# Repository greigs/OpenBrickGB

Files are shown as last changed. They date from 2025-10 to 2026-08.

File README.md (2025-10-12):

[For more info visit the hackaday writeup](https://hackaday.io/project/204088-lego-game-boy-functional-upgrade)

Watch the video (https://www.youtube.com/watch?v=JiDrCRSRUHM)

### Directory overview

- 3D Printed Parts: STL files for custom spacers and assemblies used inside the LEGO shell.
- Bill of Materials: CSVs listing components for the main PCB, button PCBs, and other parts.
- ButtonBoard PCBs: KiCad project assets and Gerbers for the button and D‑pad PCBs.
- Datasheets: Reference PDFs for key components (LCD, charger, amp, logic, regulators, etc.).
- Main PCB: KiCad project, fabrication outputs (Gerbers/DRLs), and pick‑and‑place (CPL) for the main board.
- Reference 3D Models: OBJ files used for fit checks and visualization of assemblies.
- Reference Bricklink Studio Designs: BrickLink Studio `.io` design files and a reference image for the LEGO build.

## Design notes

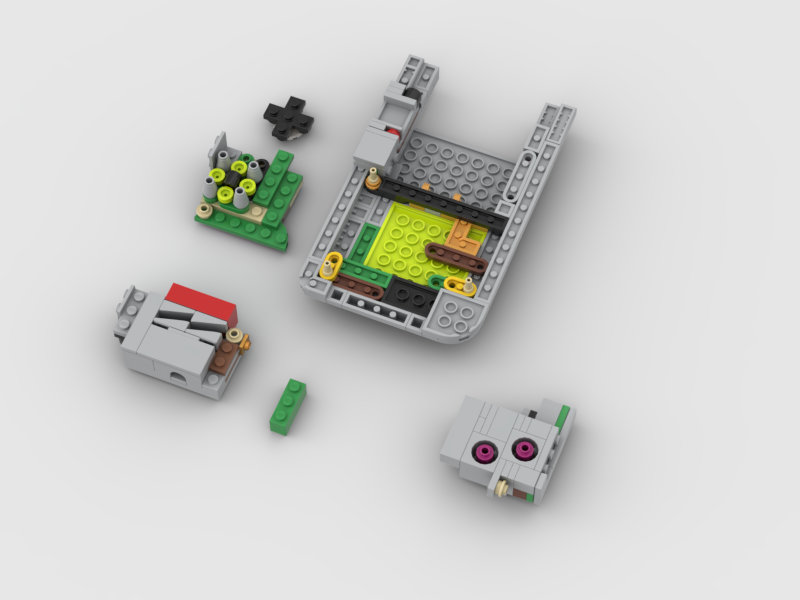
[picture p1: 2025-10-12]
Reference Bricklink Studio Designs/legogameboy_brick.png

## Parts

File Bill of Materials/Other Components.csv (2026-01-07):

Comment | Model Number | Supplier | Link | JLCPCB Part # | Quantity
2.4" LCD Screen | ER-TFT024-3 | AliExpress | https://www.aliexpress.com/item/1005008083677084.html | - | 1
USB-C Low-Profile Extension | CMZW-CF | AliExpress | https://www.aliexpress.com/item/1005008675001524.html | - | 1
Battery with PH connector | 702025 300mAh | AliExpress | https://www.aliexpress.com/item/1005009296674098.html | - | 1
Silicon Membranes for A+B buttons | - | AliExpress | https://www.aliexpress.com/item/1005007354534629.html | - | 1
LEGO Part: BRICK W. BOW (Any Colour) | 4490 | Brick Owl | https://www.brickowl.com/gb/catalog/lego-arch-1-x-3-4490 | - | 1
LEGO Part | TBD | LEGO |  | - | ?
Speaker | CMS-160903-18SP-X8 | DigiKey | https://www.digikey.co.uk/en/products/detail/same-sky-formerly-cui-devices/CMS-160903-18SP-X8/18742602 | - | 1
JST SUR Wire Jumper - 8p | A08SUR08SUR32W152A | DigiKey | https://www.digikey.co.uk/en/products/detail/jst-sales-america-inc/A08SUR08SUR32W152A/6009356 |  | 1
JST SUR Wire Jumper - 3p | A03SUR03SUR32W152B | DigiKey | https://www.digikey.co.uk/en/products/detail/jst-sales-america-inc/A03SUR03SUR32W152B/6708450 |  | 1
3M double sided adhesive | - | Stationary Shop? |  | - | 1
3D printed Part: Support for A+B Buttonboard | - | - | https://github.com/greigs/legogb/blob/main/3D%20Printed%20Parts/a_b_buttons_assembly%20v19.stl |  | 1
3D printed Part: Start + Select button assembly | - | - | https://github.com/greigs/legogb/blob/main/3D%20Printed%20Parts/start_select_assembly_with_tires%20v29.stl |  | 1
3D printed Part: USB-C Socket Housing (optional) | - | - |  | - | 1
3D printed Part: Menu Button custom Lego Piece | - | - | TBD | - | 1
3D printed Part: D-pad Spacer replacement | - | - | TBD | - | 4
MicroSD card - FAT32 Formatted | - | - | - | - | 1
Black card for covering LCD bezels (optional) | - | Stationary Shop? | - | - | 1

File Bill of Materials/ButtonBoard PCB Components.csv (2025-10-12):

Comment | Designator | Footprint | JLCPCB Part # | Purpose / Detail | Quantity
SKRRABE010 |  |  | C125046 | Low-profile tact-switch - NOTE The A + B buttons don't use these - use rubber domes instead | 6

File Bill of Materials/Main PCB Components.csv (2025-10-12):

Comment | Designator | Footprint | JLCPCB Part # | Purpose / Detail | Quantity
Conn_01x03_Socket | J6 | Connector_JST:JST_SUR_BM03B-SURS-TF_1x03-1MP_P0.80mm_Vertical | C594379 | Connector for A+B buttonboard | 1
DISP_LCD_240X320_50PIN-2.4IN | U$10 | Adafruit2.4inTFTBreakout:TFT_2.4IN_240X320_50PIN | C2828061 | 50-Pin LCD Connector | 1
USB_C_Receptacle_USB2.0_16P | J1 | Connector_USB:USB_C_Receptacle_G-Switch_GT-USB-7025 | C963213 | USB-C for power + flashing firmware | 1
MAX98357A | U4 | Package_DFN_QFN:TQFN-16-1EP_3x3mm_P0.5mm_EP1.23x1.23mm | C910544 | Sound Amplifier | 1
0.1uF | C6,C11 | Capacitor_SMD:C_0603_1608Metric | C14663 | Passive | 2
0.1nF | C8,C9 | Capacitor_SMD:C_0603_1608Metric | C14858 | Passive | 2
LED-RED | D1 | LED_SMD:LED_0603_1608Metric | C2286 | Battery Charge Indicator LED | 1
LED-GRN | D2 | LED_SMD:LED_0603_1608Metric | C2286 | Power On Indicator LED | 1
TLV75801PDRV | U2 | Package_SON:WSON-6-1EP_2x2mm_P0.65mm_EP1x1.6mm | C2876308 | Voltage Regulator | 1
1.5k | R6,R7 | Resistor_SMD:R_0603_1608Metric | C22843 | Passive | 2
ESD7104MUTAG | U3 | UDFN10_ONS | C328026 | ESD Protection | 1
B2B-PH-K-S | J3 | Connector_JST:JST_PH_S2B-PH-K_1x02_P2.00mm_Horizontal | C157932 | PH Battery Connector | 1
10uF | C4,C7 | Capacitor_SMD:C_0603_1608Metric | C19702 | Passive | 2
POWER_SW | S1 | 450404015514:450404015514 | C5446870 | Power Slide Switch | 1
BOOT | SW3,SW1 | TS-1088-AR02016:SW_TS-1088-AR02016 | C720477 | ESP32 Boot mode + Reset buttons | 2
ESP32-S3-WROOM-1-N16R8 | X1 | ESP32:ESP32S3WROOM1N8R2 | C2913202 | Main SoC | 1
200k | R3 | Resistor_SMD:R_0603_1608Metric | C25811 | Passive | 1
10 | R8 | Resistor_SMD:R_0603_1608Metric | C22859 | Passive | 1
5k | R4 | Resistor_SMD:R_0603_1608Metric | C2828621 | Passive | 1
503398-1892 | J4 | MOLEX_503398-1892:MOLEX_503398-1892 | C428492 | Passive | 1
~ | SW2 | ProLib_pcs_2025-10-09:SW-SMD_GT-TC185B-H038-L1 | C778160 | Menu Button | 1
1M | R2 | Resistor_SMD:R_0603_1608Metric | C22935 | Passive | 1
1uF | C1,C2,C3,C5,C10 | Capacitor_SMD:C_0603_1608Metric | C15849 | Passive | 5
BQ24040DSQR | U1 | BQ24040DSQR:SON40P200X200X80-11N | C81080 | Battery Management | 1
10k | R1,R5,R9,R10,R11,R12,R13,R14,R15,R16 | Resistor_SMD:R_0603_1608Metric | C25804 | Passive | 10
100k | R17 | Resistor_SMD:R_0603_1608Metric | C25803 | Passive | 1
Conn_01x08_Socket | J2 | Connector_JST:JST_SUR_BM08B-SURS-TF_1x08-1MP_P0.80mm_Vertical | C5143489 | Connector for select + start + D-pad boards | 1

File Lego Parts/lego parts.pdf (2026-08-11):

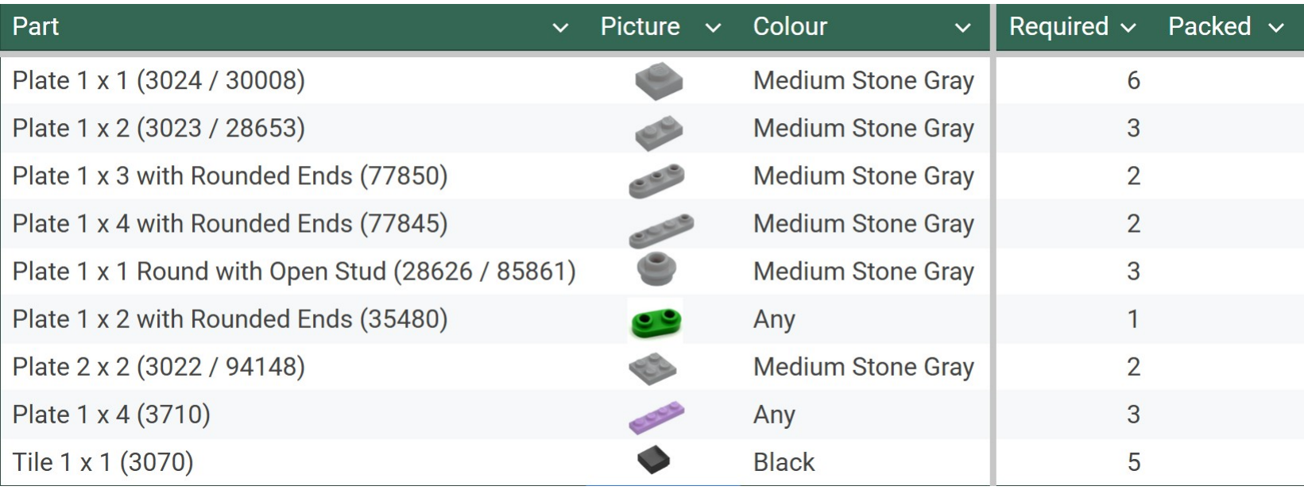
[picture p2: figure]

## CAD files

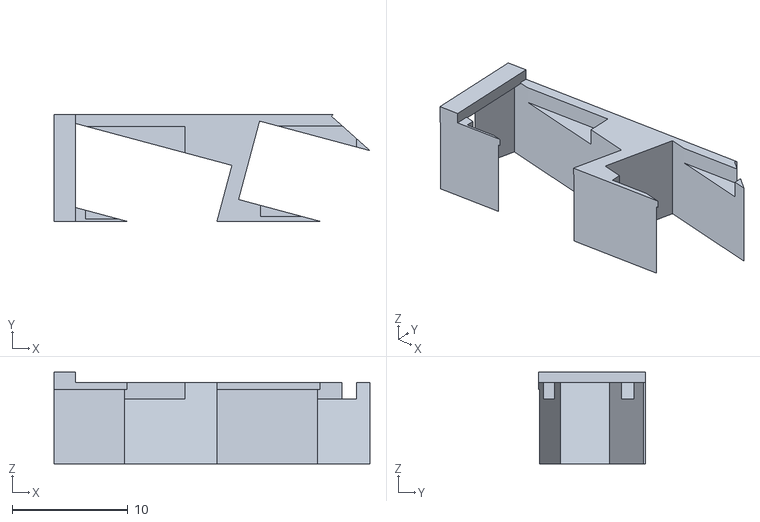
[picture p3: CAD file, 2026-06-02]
3D Printed Parts/start_select_assembly.stl
27.2 x 9.20 x 7.90

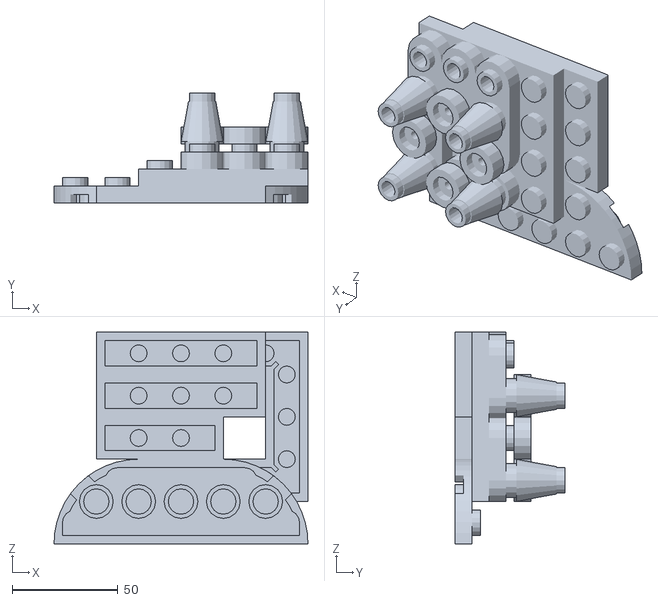
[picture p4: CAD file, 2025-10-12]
Reference 3D Models/d_pad_assembly.obj
120.0 x 52.0 x 100.0

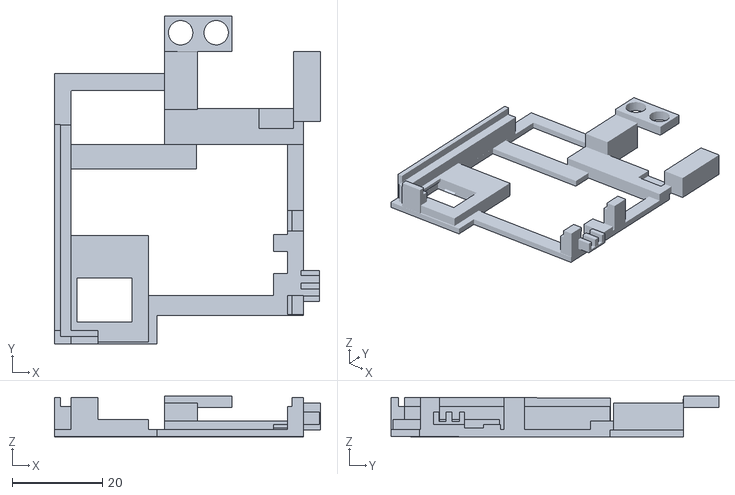
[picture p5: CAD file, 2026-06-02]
3D Printed Parts/main_frame.stl
59.0 x 72.7 x 9.06

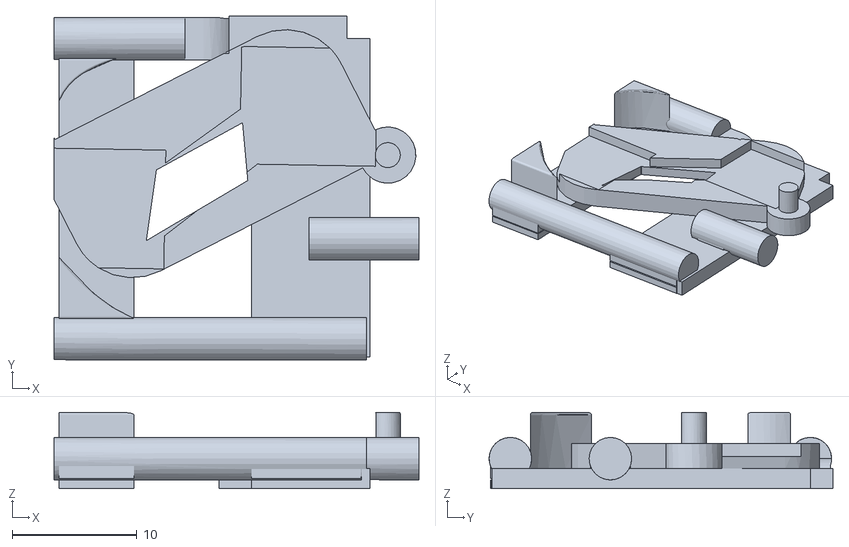
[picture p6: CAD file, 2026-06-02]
3D Printed Parts/a_b_buttons_assembly.stl
29.2 x 27.5 x 6.10

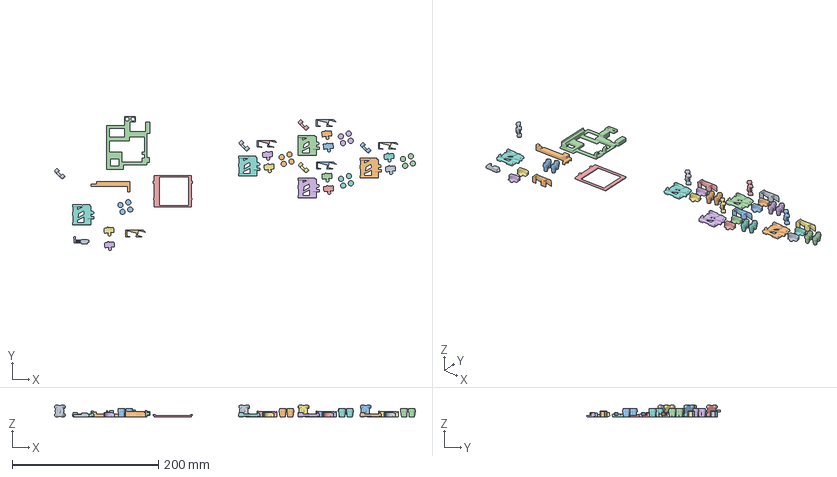
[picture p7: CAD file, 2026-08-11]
3D Printed Parts/All_Parts_v1.3mf
493.3 x 183.3 x 15.9 mm
d-pad-pivot_v20.stl x 5
spacer_6.stl
Assembly x 5
pcb_holder-speaker-5.stl
shrowd_1.stl
tire_holder_v53.stl x 10
a_b_buttons_assembly_v46.stl x 5
actuator_3.stl
start_select_assembly.stl x 5

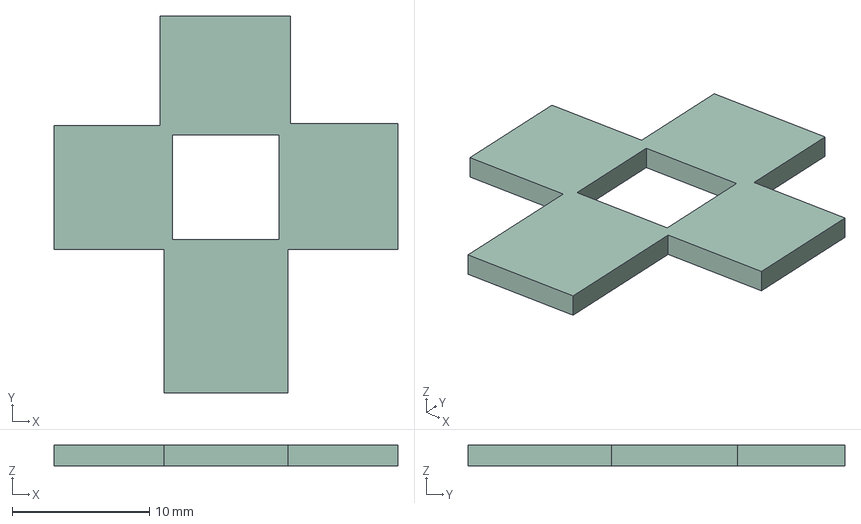
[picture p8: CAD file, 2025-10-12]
ButtonBoard PCBs/lego-gameboy-buttonboards.step
25.0 x 27.4 x 1.51 mm

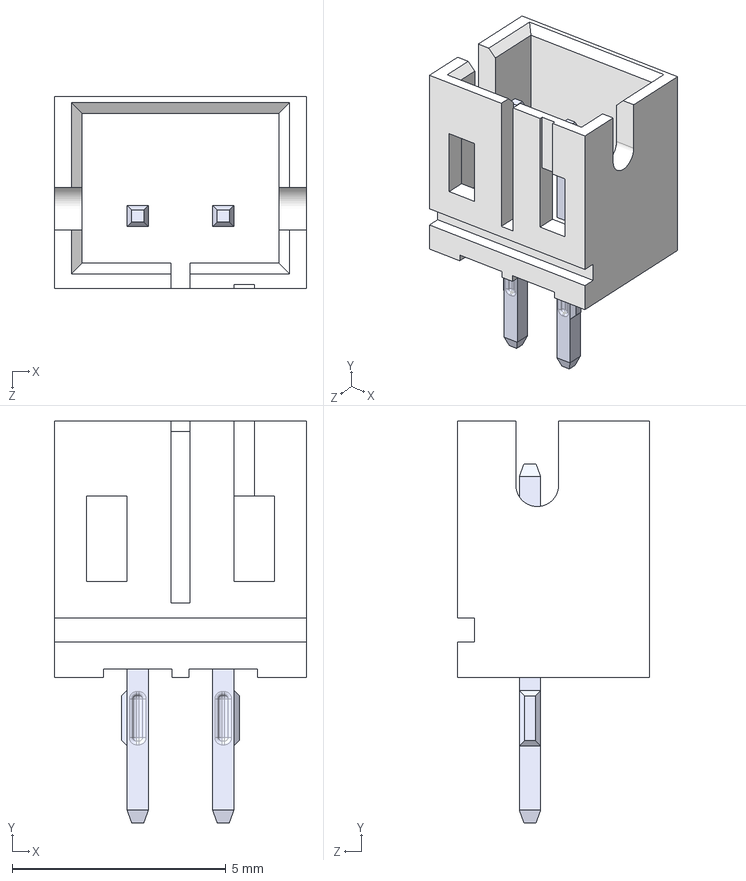
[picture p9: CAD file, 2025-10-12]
Main PCB/Kicad Components/B2B-PH-K-S/B2B-PH-K-S.step
5.90 x 9.40 x 4.50 mm

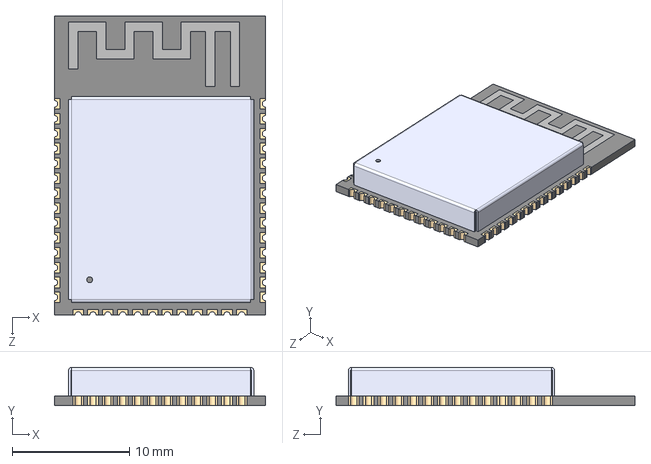
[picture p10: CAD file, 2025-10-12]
Main PCB/Kicad Components/ESP32/ESP32-S3-WROOM-1-N16R8.step
18.0 x 3.25 x 25.5 mm

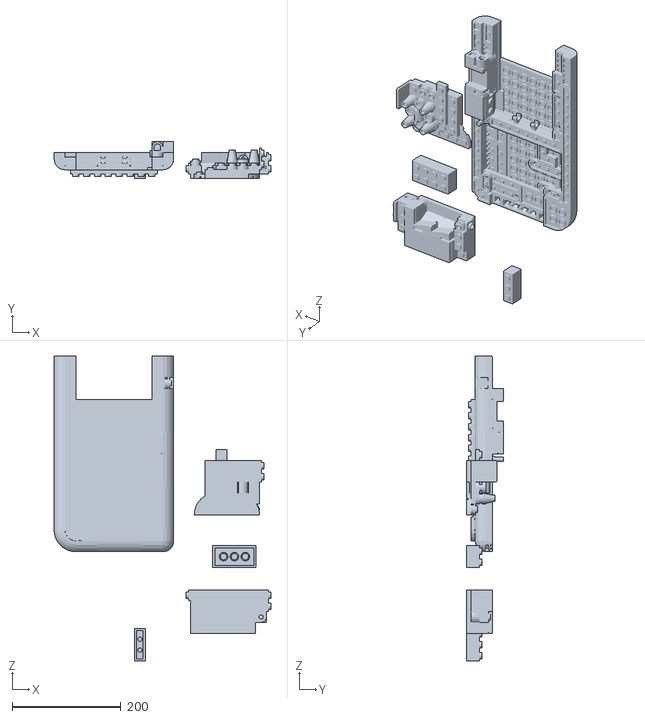
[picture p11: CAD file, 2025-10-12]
Reference 3D Models/lego_gameboy.obj
398.7 x 67.8 x 561.0

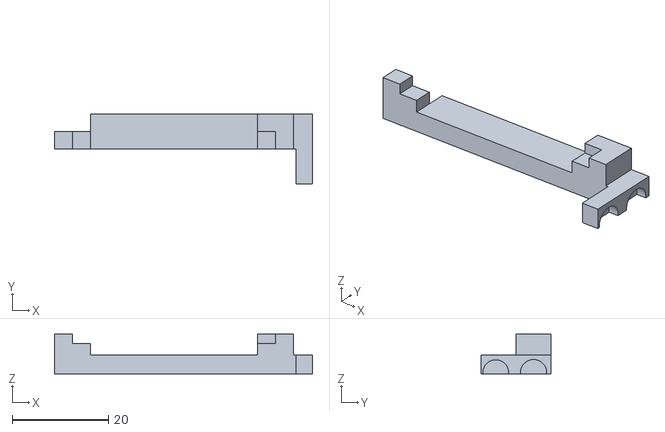
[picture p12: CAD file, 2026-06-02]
3D Printed Parts/lcd_support.stl
53.6 x 14.6 x 8.27

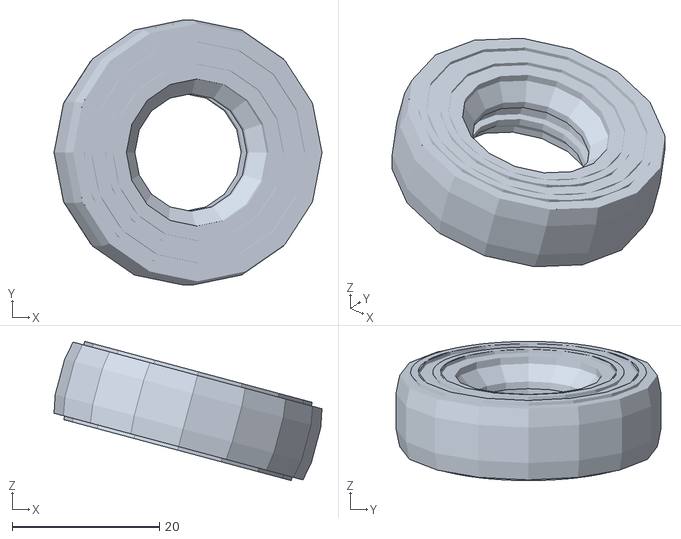
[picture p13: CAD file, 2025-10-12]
Reference 3D Models/tire.obj
36.4 x 36.0 x 18.9

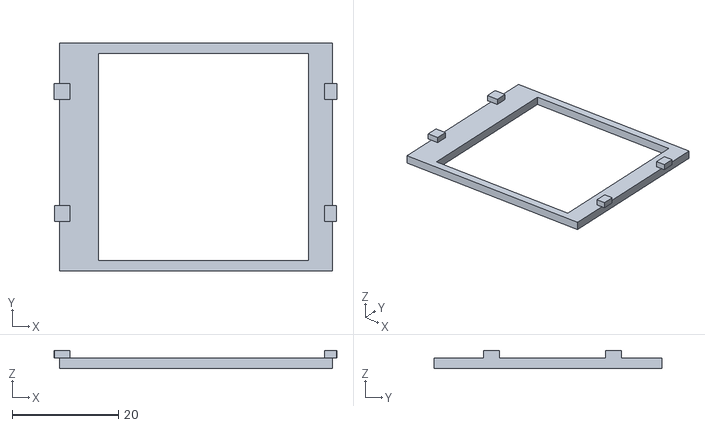
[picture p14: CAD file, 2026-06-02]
3D Printed Parts/screen_shrowd.stl
53.3 x 43.0 x 3.40

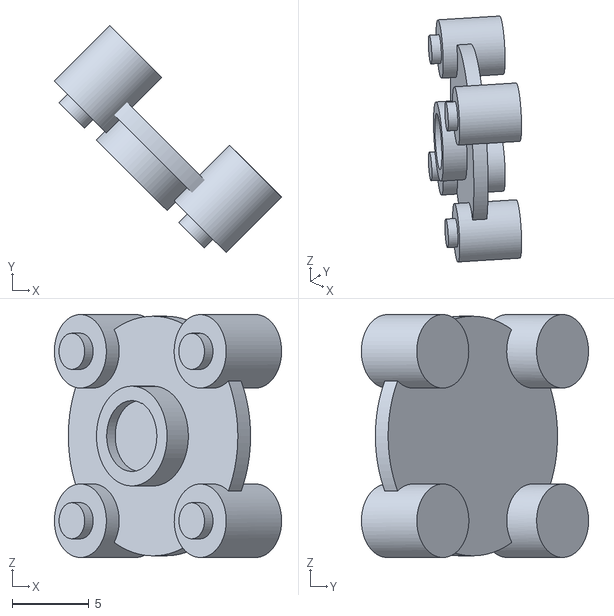
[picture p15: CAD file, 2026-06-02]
3D Printed Parts/dpad_support.stl
14.8 x 14.8 x 15.9

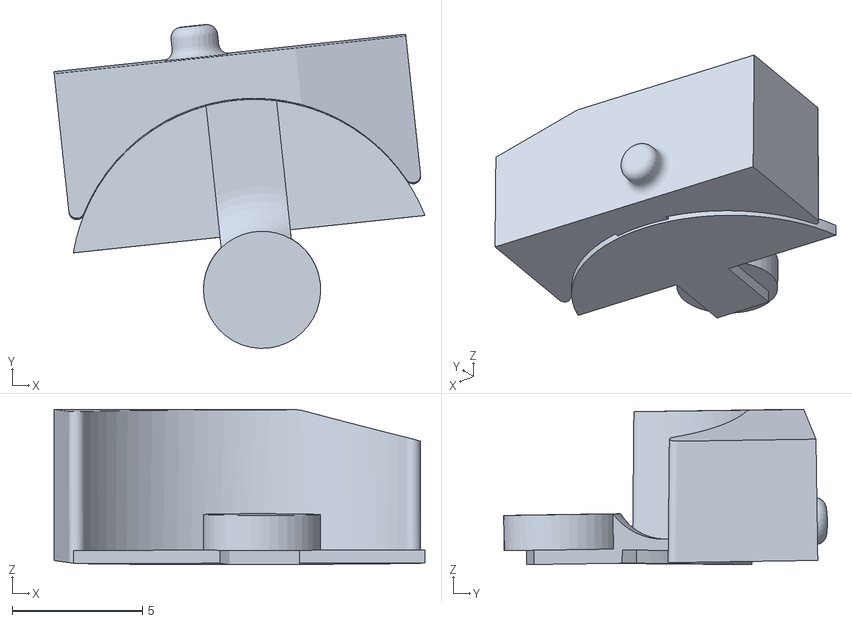
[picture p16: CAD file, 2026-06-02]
3D Printed Parts/tire_holder.stl
14.2 x 12.4 x 5.96

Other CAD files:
3D Printed Parts/cone.stl
3D Printed Parts/actuator.stl
Main PCB/Kicad Components/450404015514/450404015514.step
Main PCB/Kicad Components/BQ24040DSQR/BQ24040DSQR.step

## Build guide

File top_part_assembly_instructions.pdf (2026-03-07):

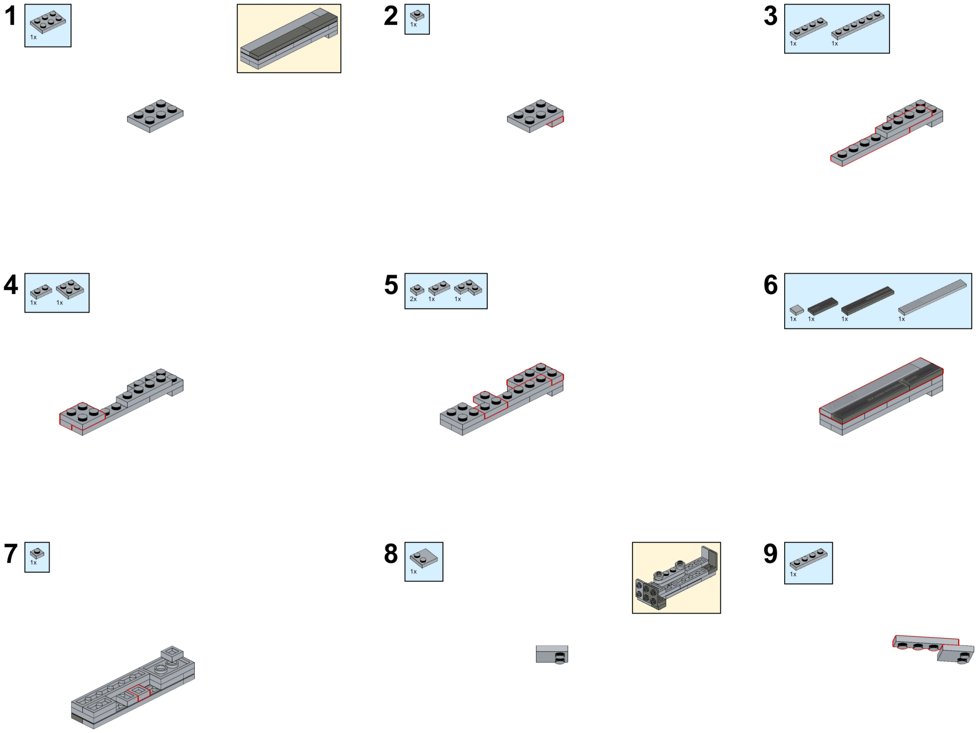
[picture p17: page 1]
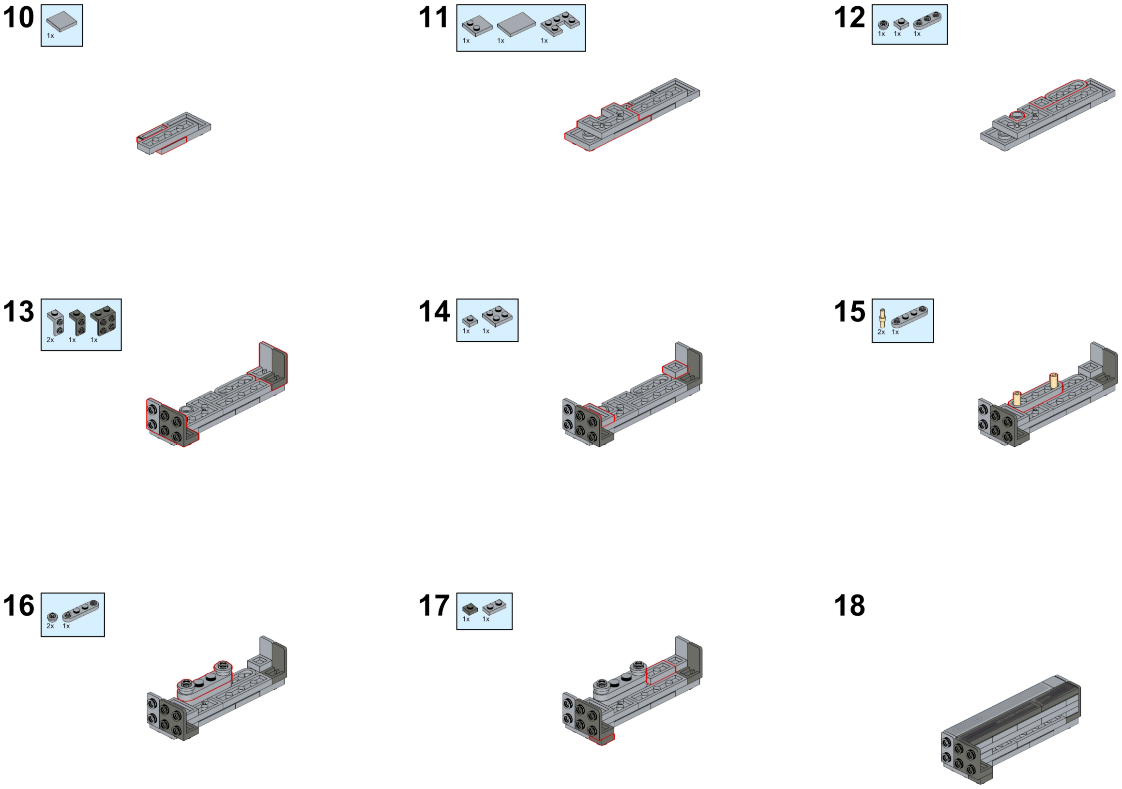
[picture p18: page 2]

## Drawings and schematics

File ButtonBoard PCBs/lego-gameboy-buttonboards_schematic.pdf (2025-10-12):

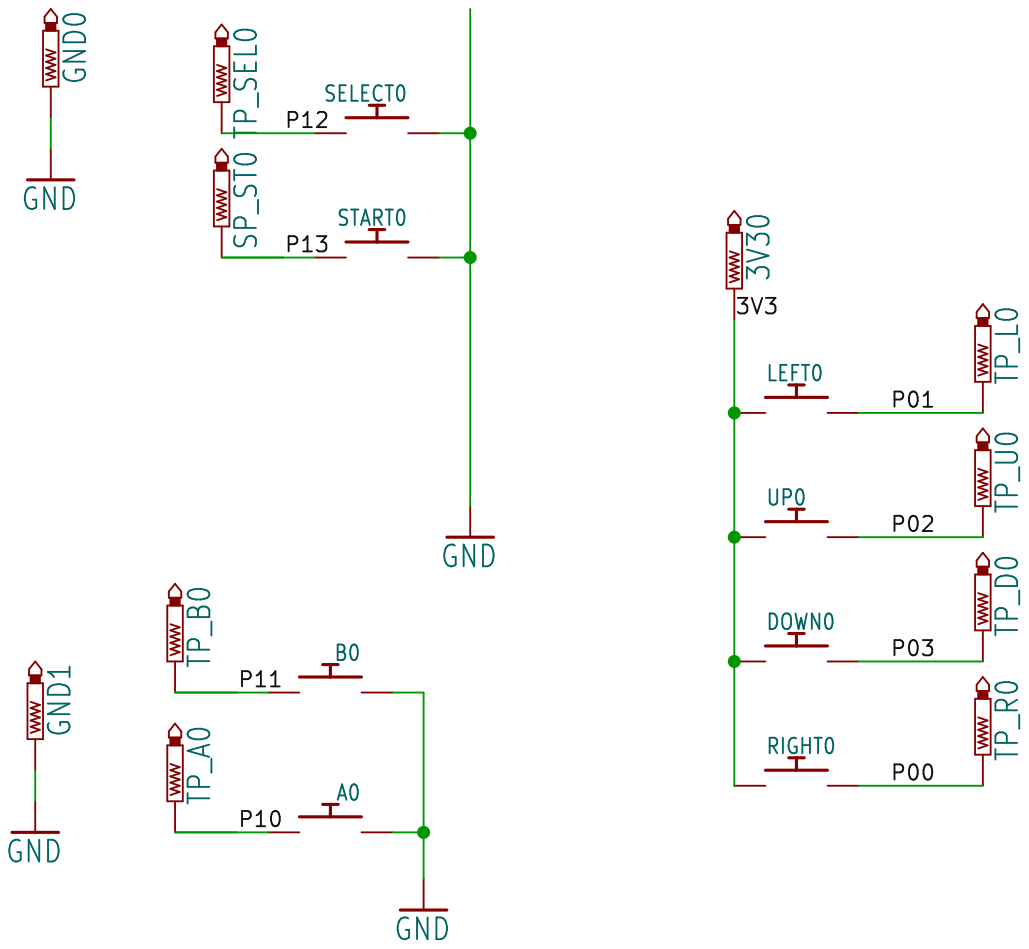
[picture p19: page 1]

Id: 1/1 Title: Lego Game Boy Button Boards

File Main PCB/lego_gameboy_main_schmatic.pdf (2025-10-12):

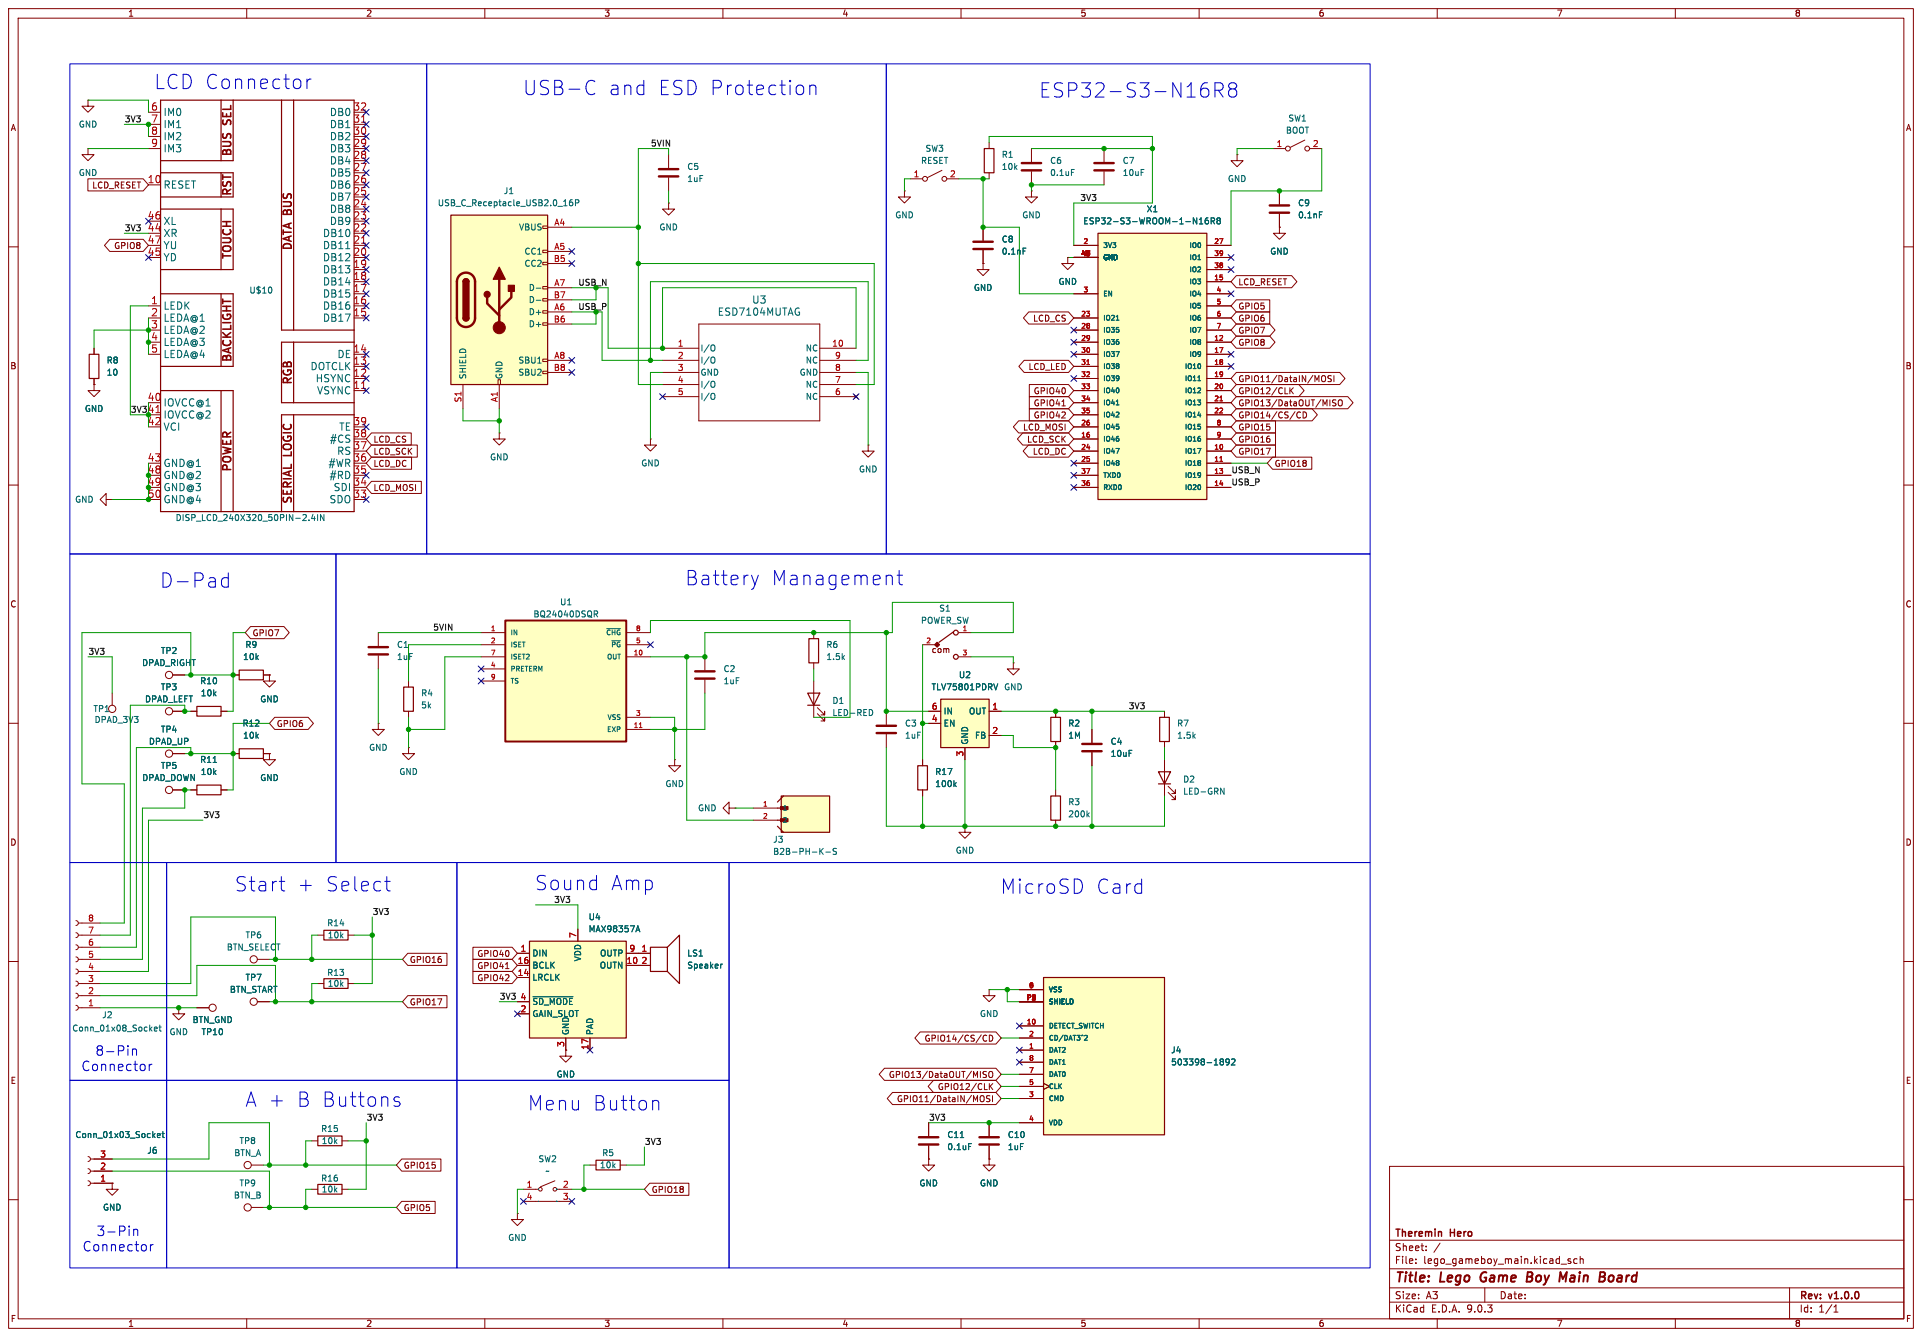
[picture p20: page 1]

USB-C and ESD Protection

GPIO11/DataIN/MOSI GPIO12/CLK GPIO15 GPIO14/CS/CD GPIO16 GPIO17

7 PAD 17 OUTP 9 OUTN 10 U4 MAX98357A GND GND

GPIO14/CS/CD GPIO13/DataOUT/MISO

Id: 1/1 Title: Lego Game Boy Main Board

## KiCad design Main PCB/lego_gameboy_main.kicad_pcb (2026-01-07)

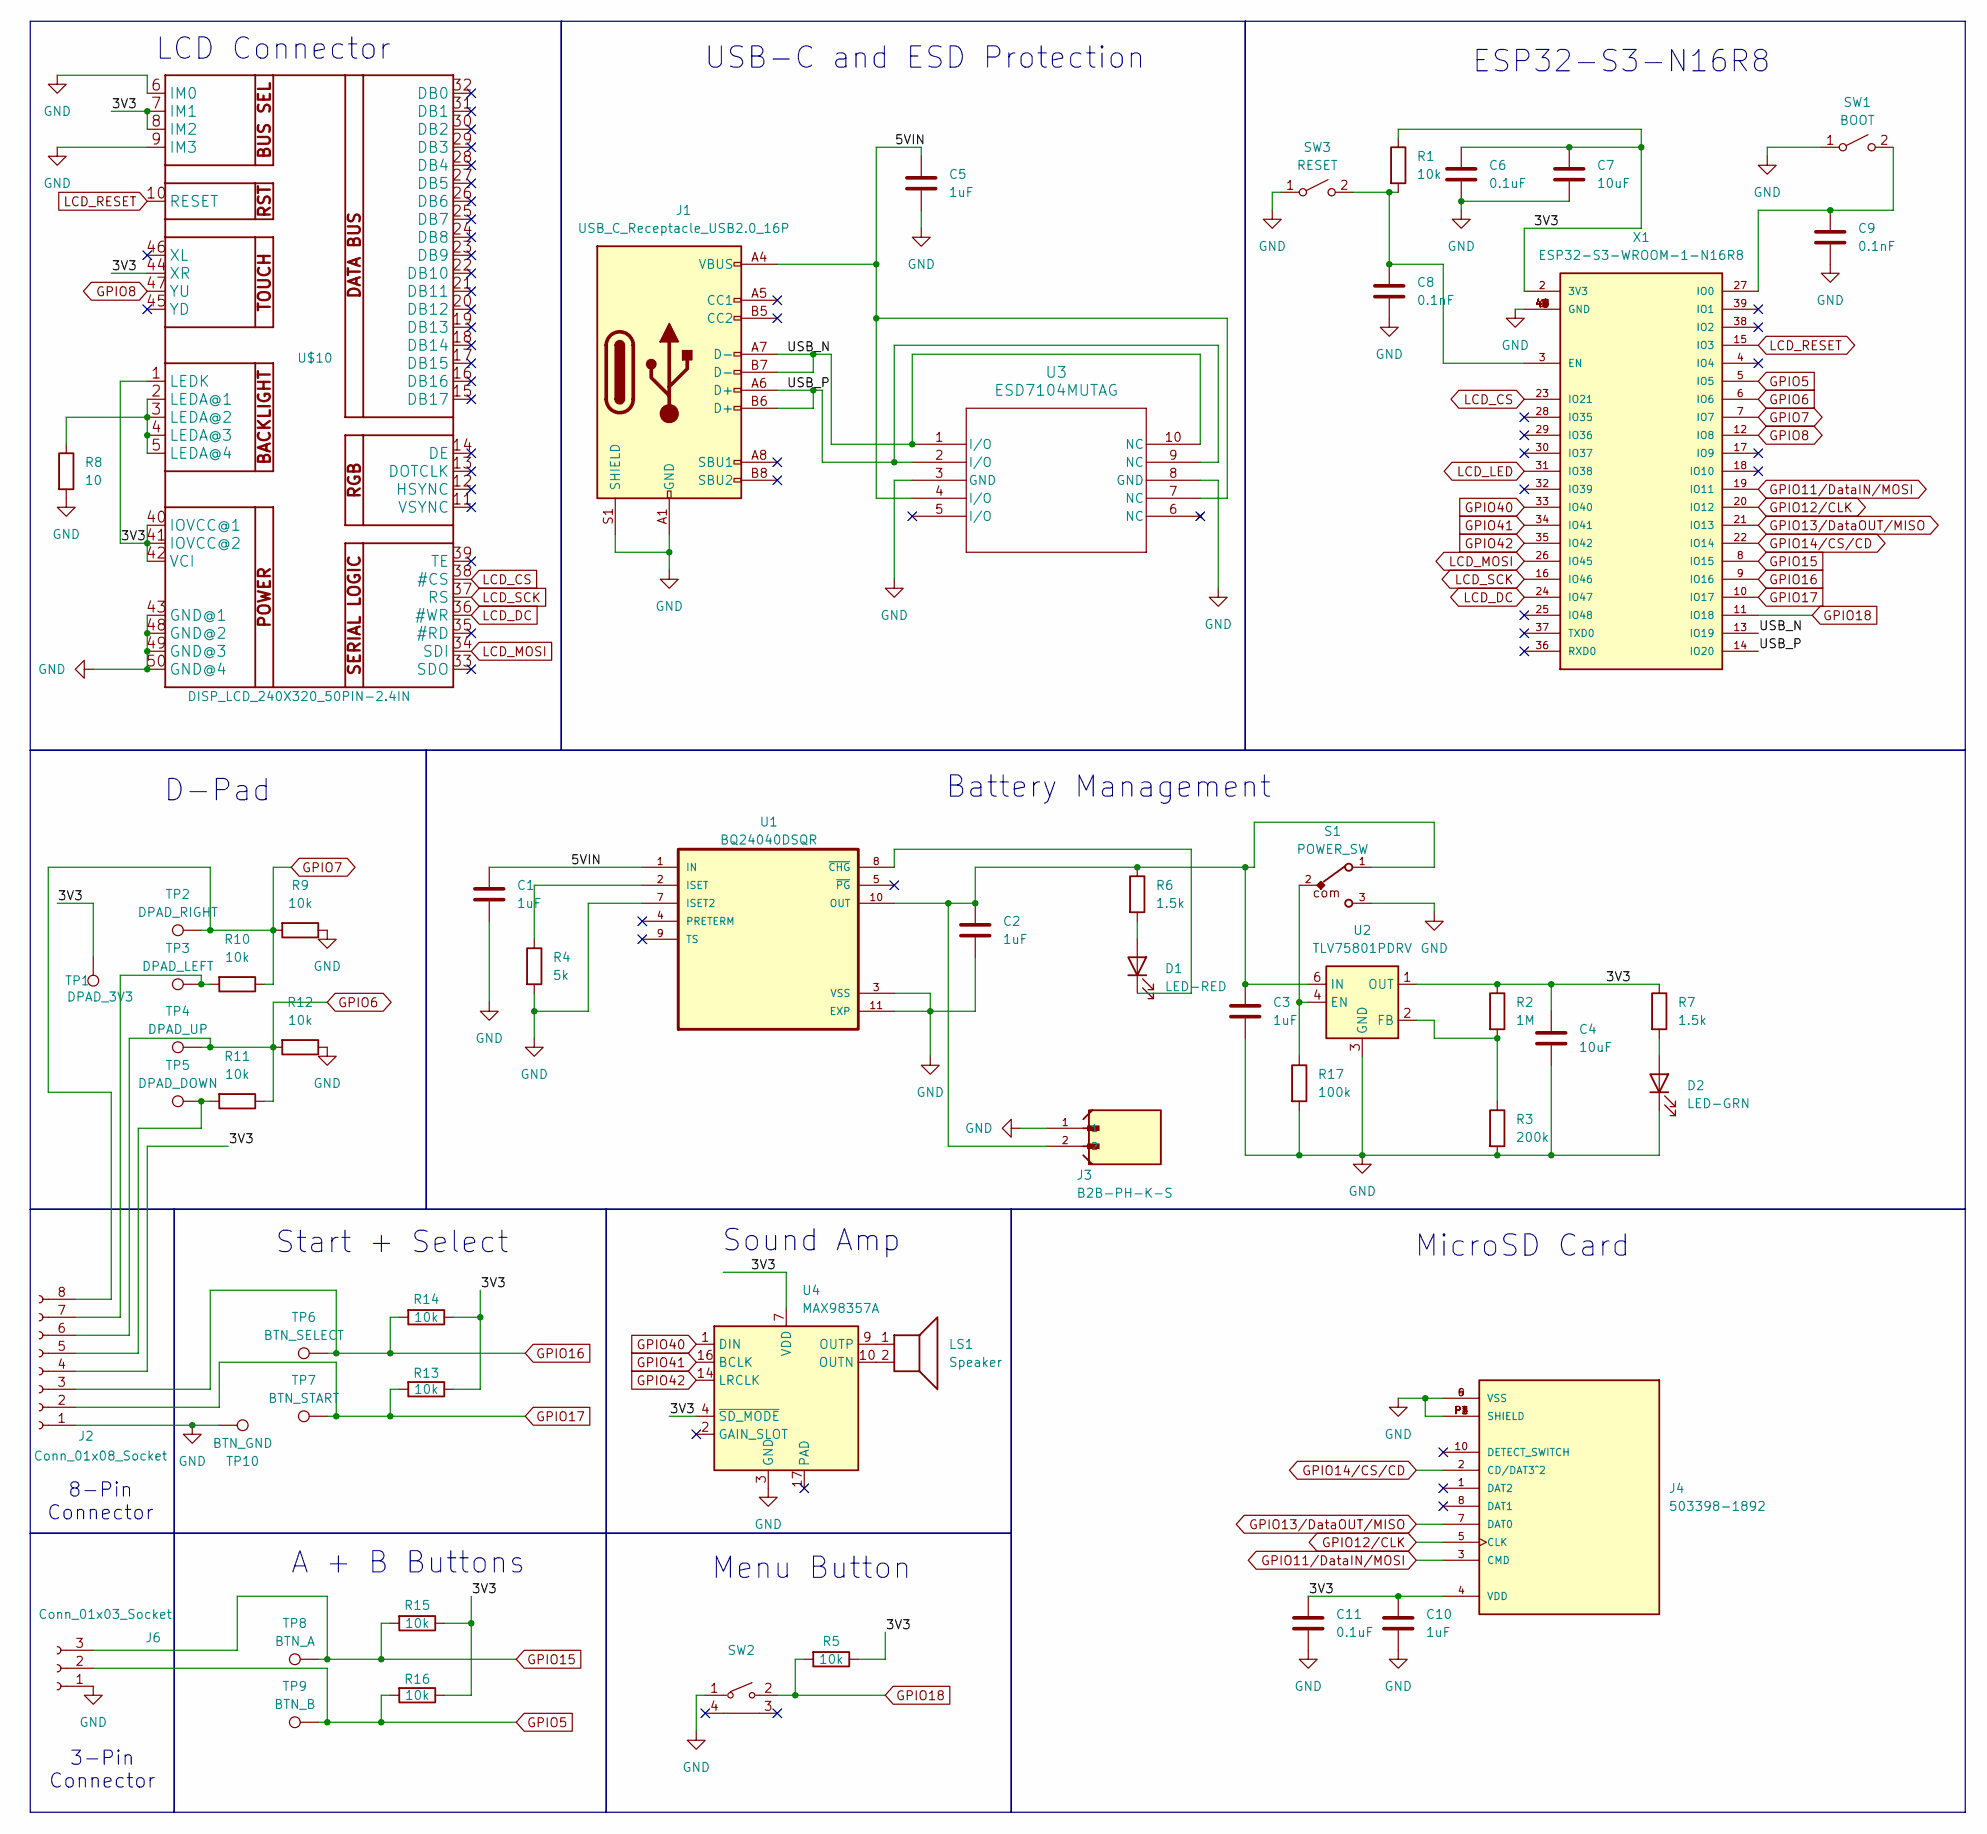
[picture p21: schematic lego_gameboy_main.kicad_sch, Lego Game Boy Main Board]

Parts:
C1, C2, C3, C5, C10: 1uF; C_0603_1608Metric
C4, C7: 10uF; C_0603_1608Metric
C6, C11: 0.1uF; C_0603_1608Metric
C8, C9: 0.1nF; C_0603_1608Metric
D1: LED-RED; LED_0603_1608Metric
D2: LED-GRN; LED_0603_1608Metric
J1: USB_C_Receptacle_USB2.0_16P; USB_C_Receptacle_G-Switch_GT-USB-7025
J2: Conn_01x08_Socket; JST_SUR_BM08B-SURS-TF_1x08-1MP_P0.80mm_Vertical
J3: B2B-PH-K-S; JST_PH_S2B-PH-K_1x02_P2.00mm_Horizontal
J4: 503398-1892; MOLEX_503398-1892; PARTREV 0; DigiKey_Part_Number WM11190CT-ND
J6: Conn_01x03_Socket; JST_SUR_BM03B-SURS-TF_1x03-1MP_P0.80mm_Vertical
LS1: Speaker; Speaker_CUI_CMR-1206S-67
R1, R5, R9, R10, R11, R12, R13, R14, R15, R16: 10k; R_0603_1608Metric
R2: 1M; R_0603_1608Metric
R3: 200k; R_0603_1608Metric
R4: 5k; R_0603_1608Metric
R6, R7: 1.5k; R_0603_1608Metric
R8: 10; R_0603_1608Metric
R17: 100k; R_0603_1608Metric
S1: POWER_SW; 450404015514
SW1: BOOT; SW_TS-1088-AR02016
SW2: SW-SMD_GT-TC185B-H038-L1; Manufacturer Part GT-TC185B-H038-L1; LCSC Part Name 4.9*5.5*3.8mm 卧贴 轻触开关
SW3: RESET; SW_TS-1088-AR02016
TP1: DPAD_3V3; TestPoint_Pad_D1.0mm
TP2: DPAD_RIGHT; TestPoint_Pad_D1.0mm
TP3: DPAD_LEFT; TestPoint_Pad_D1.0mm
TP4: DPAD_UP; TestPoint_Pad_D1.0mm
TP5: DPAD_DOWN; TestPoint_Pad_D1.0mm
TP6: BTN_SELECT; TestPoint_Pad_D1.0mm
TP7: BTN_START; TestPoint_Pad_D1.0mm
TP8: BTN_A; TestPoint_Pad_D1.0mm
TP9: BTN_B; TestPoint_Pad_D1.0mm
TP10: BTN_GND; TestPoint_Pad_D1.0mm
U1: BQ24040DSQR; SON40P200X200X80-11N
U2: TLV75801PDRV; WSON-6-1EP_2x2mm_P0.65mm_EP1x1.6mm
U3: ESD7104MUTAG; UDFN10_ONS
U4: MAX98357A; TQFN-16-1EP_3x3mm_P0.5mm_EP1.23x1.23mm
U$10: DISP_LCD_240X320_50PIN-2.4IN; TFT_2.4IN_240X320_50PIN
X1: ESP32-S3-WROOM-1-N16R8; ESP32S3WROOM1N8R2; MANUFACTURER_PART_NUMBER ESP32-S3-WROOM-1-N16R8

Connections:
/3V3: C4.1, C6.1, C7.1, C10.1, C11.1, J2.4, J4.4 (VDD), R1.1, R2.1, R5.1, R7.1, R13.1, R14.1, R15.1, R16.1, TP1.1, U2.1 (OUT), U4.4 (~SD_MODE), U4.7 (VDD), U4.8 (VDD), U$10.1 (LEDK), U$10.7 (IM1), U$10.8 (IM2), U$10.40 (IOVCC@1), U$10.41 (IOVCC@2), U$10.42 (VCI), U$10.44 (XR), X1.2 (3V3)
/5VIN: C1.1, C5.1, J1.A4 (VBUS), J1.A9 (VBUS), J1.B4 (VBUS), J1.B9 (VBUS), U1.1 (IN), U3.4 (I/O), U3.7 (NC)
/USB_N: J1.A7 (D-), J1.B7 (D-), U3.1 (I/O), U3.10 (NC), X1.13 (IO19)
/USB_P: J1.A6 (D+), J1.B6 (D+), U3.2 (I/O), U3.9 (NC), X1.14 (IO20)
GND: C1.2, C2.2, C3.2, C4.2, C5.2, C6.2, C7.2, C8.2, C9.2, C10.2, C11.2, D2.1 (K), J1.A1 (GND), J1.A12 (GND), J1.B1 (GND), J1.B12 (GND), J1.S1 (SHIELD), J2.1, J3.1, J4.6 (VSS), J4.9 (VSS), J4.P1 (SHIELD), J4.P2 (SHIELD), J4.P3 (SHIELD), J4.P4 (SHIELD), J6.1, R3.2, R4.2, R8.2, R9.1, R12.1, R17.2, S1.3, SW1.1 (A), SW2.1, SW3.1 (A), TP10.1, U1.3 (VSS), U1.7 (ISET2), U1.11 (EXP), U2.3 (GND), U2.7 (GND), U3.3 (GND), U3.8 (GND), U4.3 (GND), U4.11 (GND), U4.15 (GND), U$10.6 (IM0), U$10.9 (IM3), U$10.43 (GND@1), U$10.48 (GND@2), U$10.49 (GND@3), U$10.50 (GND@4), X1.1 (GND), X1.40 (GND), X1.41 (GND), X1.42 (GND), X1.43 (GND), X1.44 (GND), X1.45 (GND), X1.46 (GND), X1.47 (GND), X1.48 (GND), X1.49 (GND)
GPIO5: J6.2, R16.2, TP9.1, X1.5 (IO5)
GPIO6: J2.6, R11.1, R12.2, TP4.1, X1.6 (IO6)
GPIO7: J2.8, R9.2, R10.1, TP2.1, X1.7 (IO7)
GPIO8: U$10.47 (YU), X1.12 (IO8)
GPIO11/DataIN/MOSI: J4.3 (CMD), X1.19 (IO11)
GPIO12/CLK: J4.5 (CLK), X1.20 (IO12)
GPIO13/DataOUT/MISO: J4.7 (DAT0), X1.21 (IO13)
GPIO14/CS/CD: J4.2 (CD/DAT3^2), X1.22 (IO14)
GPIO15: J6.3, R15.2, TP8.1, X1.8 (IO15)
GPIO16: J2.3, R14.2, TP6.1, X1.9 (IO16)
GPIO17: J2.2, R13.2, TP7.1, X1.10 (IO17)
GPIO18: R5.2, SW2.2, X1.11 (IO18)
GPIO40: U4.1 (DIN), X1.33 (IO40)
GPIO41: U4.16 (BCLK), X1.34 (IO41)
GPIO42: U4.14 (LRCLK), X1.35 (IO42)
LCD_CS: U$10.38 (#CS), X1.23 (IO21)
LCD_DC: U$10.36 (#WR), X1.24 (IO47)
LCD_LED: X1.31 (IO38)
LCD_MOSI: U$10.34 (SDI), X1.26 (IO45)
LCD_RESET: U$10.10 (RESET), X1.15 (IO3)
LCD_SCK: U$10.37 (RS), X1.16 (IO46)
unnamed: D1.2 (A), R6.2
unnamed: D1.1 (K), U1.8 (~CHG)
unnamed: D2.2 (A), R7.2
unnamed: J2.5, R11.2, TP5.1
unnamed: J2.7, R10.2, TP3.1
unnamed: C9.1, SW1.2 (B), X1.27 (IO0)
unnamed: C8.1, R1.2, SW3.2 (B), X1.3 (EN)
unnamed: R4.1, U1.2 (ISET)
unnamed: C2.1, C3.1, J3.2, R6.1, S1.1, U1.10 (OUT), U2.6 (IN)
unnamed: R17.1, S1.2, U2.4 (EN)
unnamed: R2.2, R3.1, U2.2 (FB)
unnamed: LS1.2, U4.10 (OUTN)
unnamed: LS1.1, U4.9 (OUTP)
unnamed: R8.1, U$10.2 (LEDA@1), U$10.3 (LEDA@2), U$10.4 (LEDA@3), U$10.5 (LEDA@4)

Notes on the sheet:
Menu Button
Sound Amp
USB-C and ESD Protection
Battery Management
D-Pad
A + B Buttons
MicroSD Card
8-Pin Connector
Start + Select
3-Pin Connector
LCD Connector
ESP32-S3-N16R8

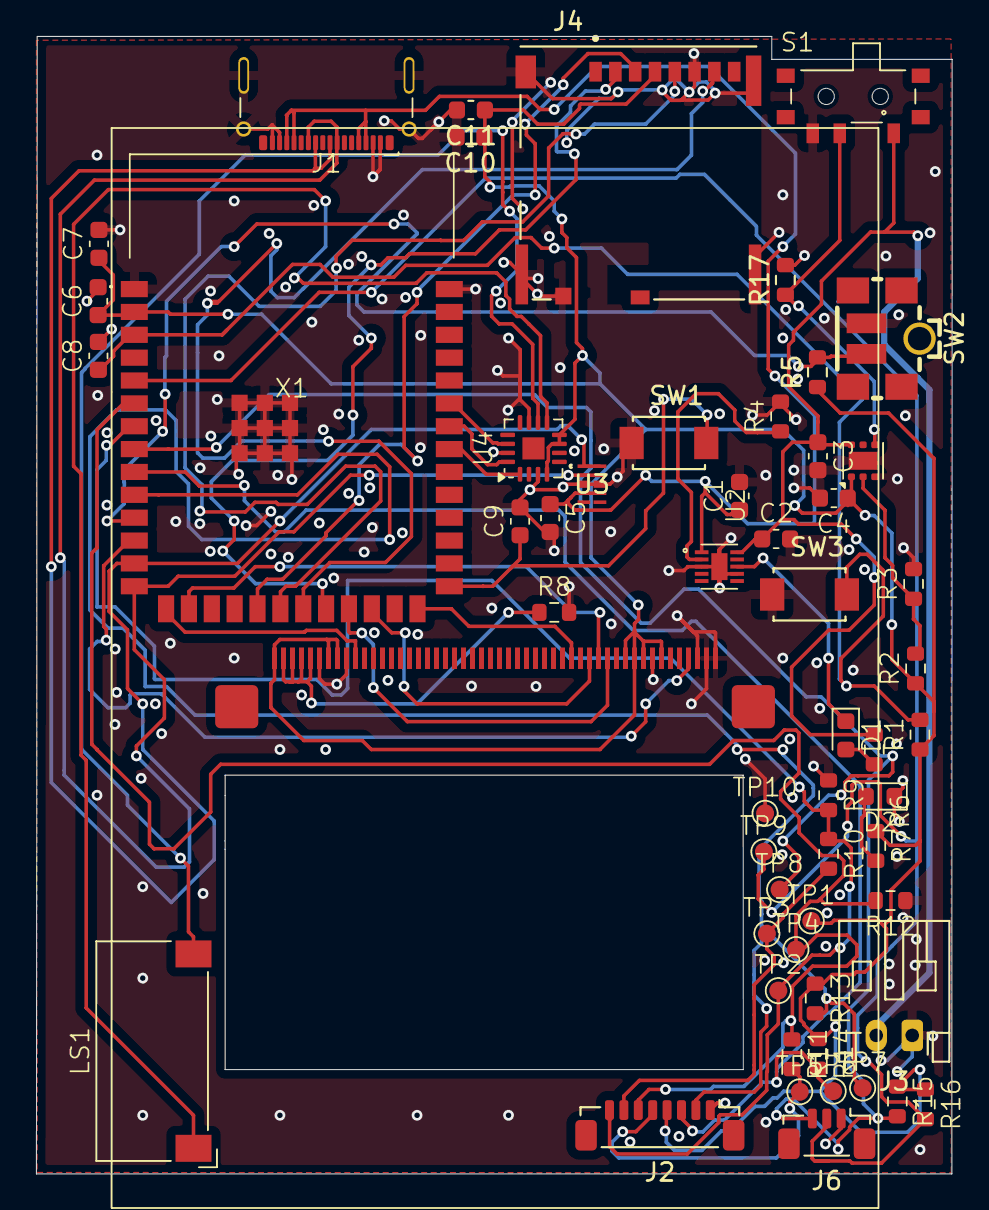
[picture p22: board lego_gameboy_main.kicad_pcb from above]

Board: 4 copper layers, 50.9 x 63.2 mm, 56 parts (0 on the bottom side), 39 nets.

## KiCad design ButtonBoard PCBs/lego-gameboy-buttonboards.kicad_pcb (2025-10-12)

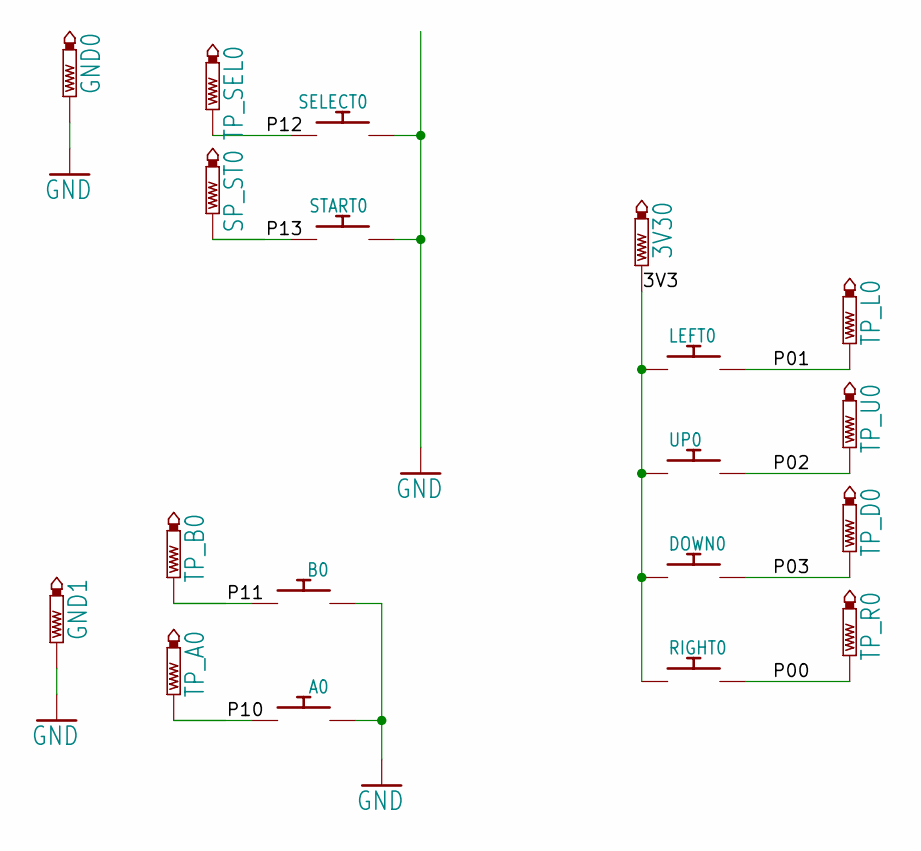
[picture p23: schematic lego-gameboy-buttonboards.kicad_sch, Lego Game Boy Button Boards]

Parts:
3V30: PTR1TP20R; TP20R
A0: DMG-BTN; DMG_BTN1
B0: DMG-BTN; DMG_BTN1
DOWN0: DMG-BTN; DMG_BTN1
GND0, GND1: PTR1TP20R; TP20R
LEFT0: DMG-BTN; DMG_BTN1
RIGHT0: DMG-BTN; DMG_BTN1
SELECT0: DMG-BTN; DMG_BTN2_TACT2
SP_ST0: PTR1TP20R; TP20R
START0: DMG-BTN; DMG_BTN2_TACT2
TP_A0: PTR1TP20R; TP20R
TP_B0: PTR1TP20R; TP20R
TP_D0: PTR1TP20R; TP20R
TP_L0: PTR1TP20R; TP20R
TP_R0: PTR1TP20R; TP20R
TP_SEL0: PTR1TP20R; TP20R
TP_U0: PTR1TP20R; TP20R
UP0: DMG-BTN; DMG_BTN1

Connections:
/3V3: 3V30.TP, DOWN0.P$2, LEFT0.P$2, RIGHT0.P$2, UP0.P$2
/P00: RIGHT0.P$1, TP_R0.TP
/P01: LEFT0.P$1, TP_L0.TP
/P02: TP_U0.TP, UP0.P$1
/P03: DOWN0.P$1, TP_D0.TP
/P10: A0.P$1, TP_A0.TP
/P11: B0.P$1, TP_B0.TP
/P12: SELECT0.P$2, TP_SEL0.TP; also elsewhere on the board
/P13: SP_ST0.TP, START0.P$2; also elsewhere on the board
GND: A0.P$2, B0.P$2, GND0.TP, GND1.TP, SELECT0.P$1, START0.P$1; also elsewhere on the board

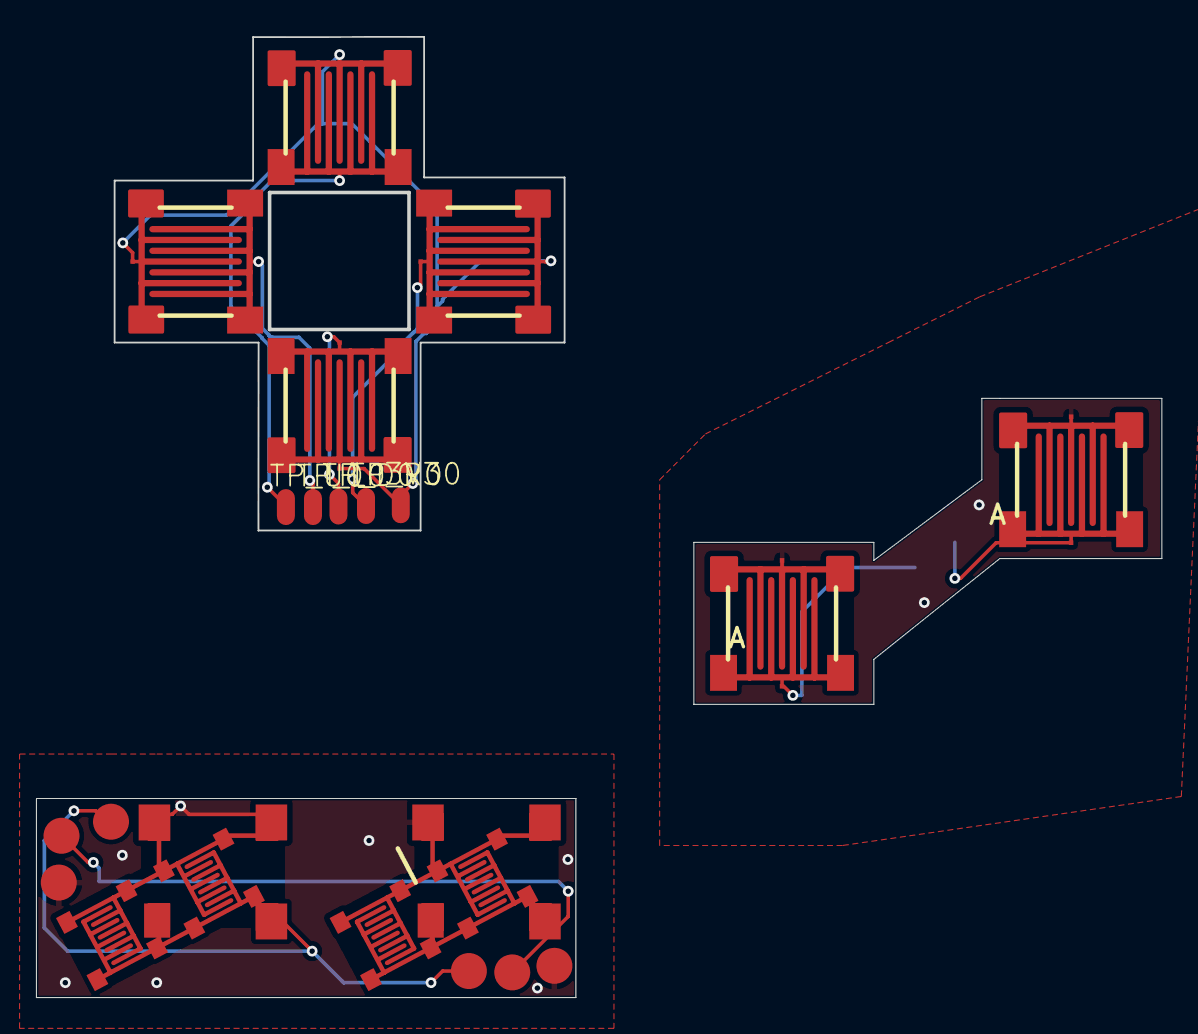
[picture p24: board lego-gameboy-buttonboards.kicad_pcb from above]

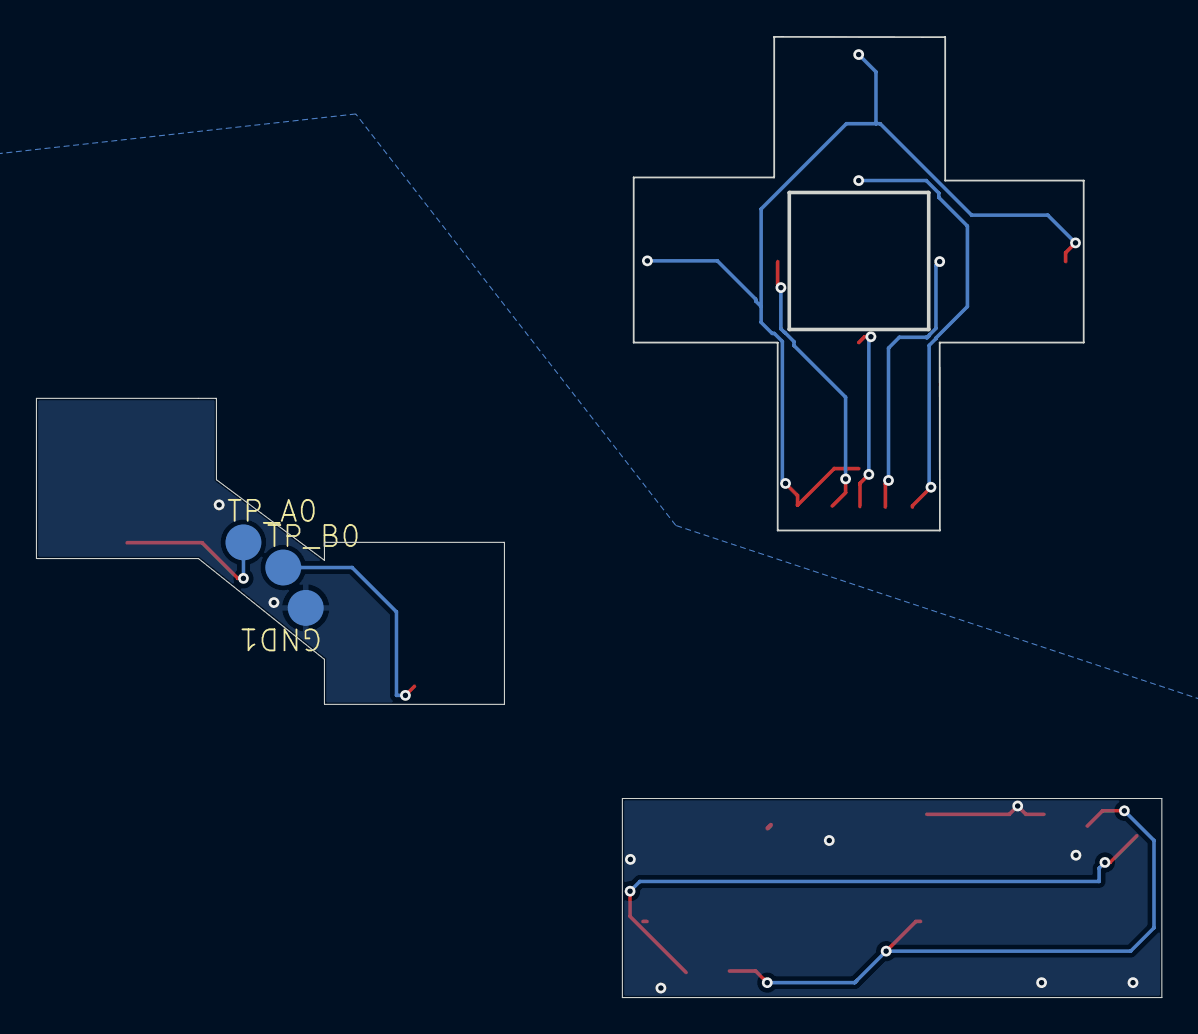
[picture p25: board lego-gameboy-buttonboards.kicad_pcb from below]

Board: 2 copper layers, 62.5 x 53.4 mm, 22 parts (3 on the bottom side), 10 nets.

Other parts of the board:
GND0#2: PTR1TP20R; TP20R
SP_ST0#2: PTR1TP20R; TP20R
TP_SEL0#2: PTR1TP20R; TP20R

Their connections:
/P12: TP_SEL0#2.TP; also elsewhere on the board
/P13: SP_ST0#2.TP; also elsewhere on the board
GND: GND0#2.TP; also elsewhere on the board

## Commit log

2025-10-12 v1 design cleaned up
    [450404015514.step, Adafruit 2.4in TFT Breakout.sch, B2B-PH-K-S.step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]
2025-10-12 updated BOM
    [ButtonBoard PCB Components.csv, Main PCB Components.csv, Other Components.csv]
2025-10-12 update links
    [Other Components.csv]
2025-10-12 added every other component needed
    [Other Components.csv]
2026-01-07 moved usb-c to top edge
    [Other Components.csv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]
2026-06-02 3d printable files from v1 of the kit
    [a_b_buttons_assembly v19.stl, a_b_buttons_assembly.stl, actuator.stl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]
2026-08-11 add lego parts checklist
    [All_Parts_v1.3mf]
